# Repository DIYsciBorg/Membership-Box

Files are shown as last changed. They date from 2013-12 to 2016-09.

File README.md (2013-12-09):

Membership-Box
==============

A membership and donations payment box, utilizing Arduino, LCD, thermal printer and bill validator.

Arduino code: THS_Membership_Box.ino
EagleCAD files: .brd, .pro, .sch
Images of the board and schematic in png for quick viewing.

This is a membership payment and donation box. It is comprised of an Arduino with 
custom shield, 20x2 VFD display, two illuminated buttons, a thermal printer and a 
bill acceptor.

The bill acceptor is model NV10USB, by Innovative Technologies. It is programmed
to accept Japanese yen (1000, 5000, and 10000).

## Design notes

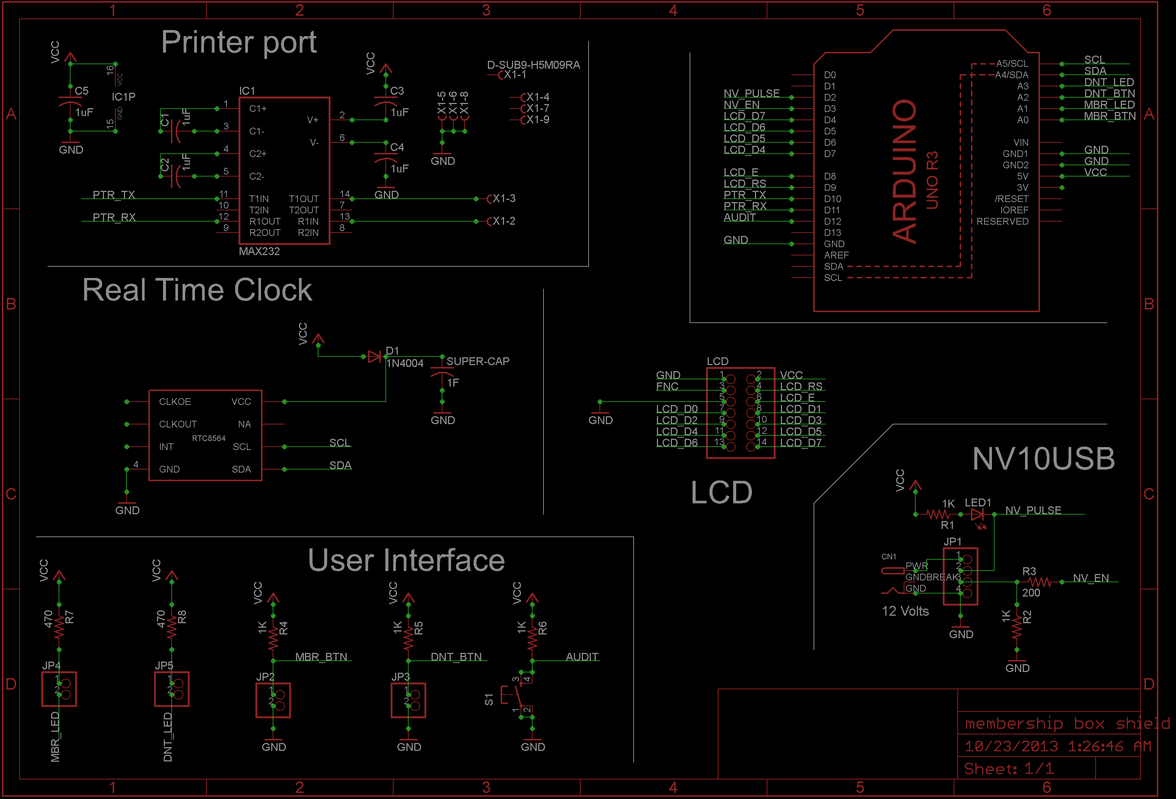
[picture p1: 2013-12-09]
Eagle/membership box schematic.png

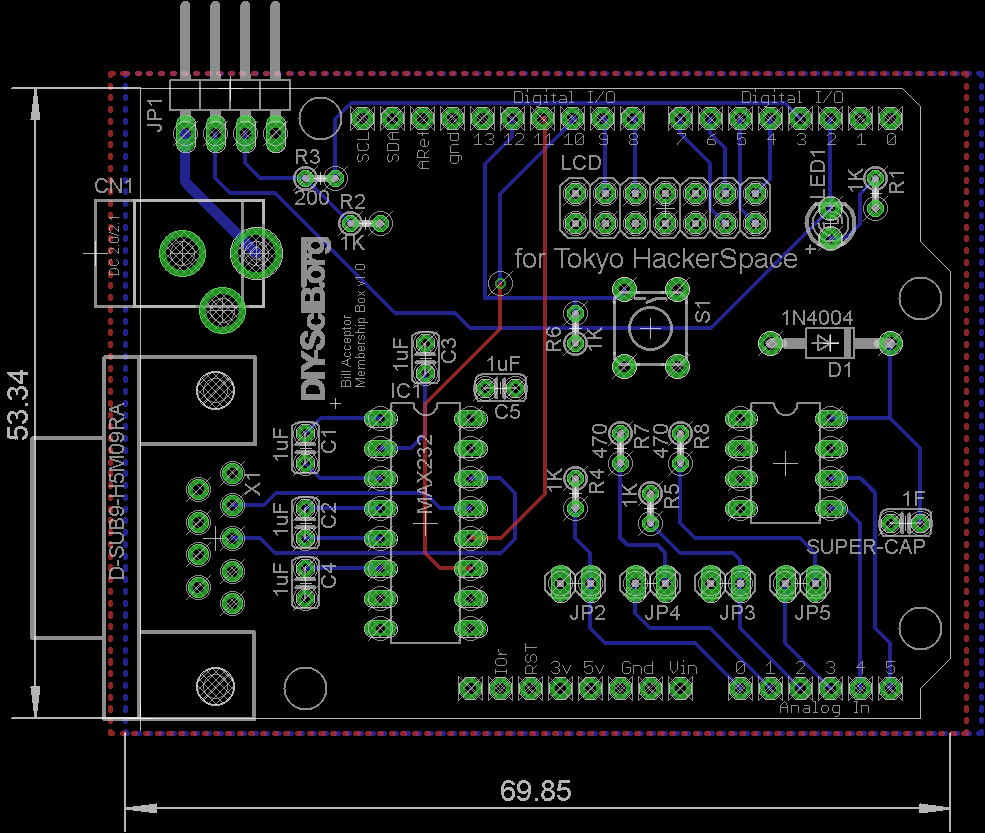
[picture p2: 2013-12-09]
Eagle/membership box pcb.png

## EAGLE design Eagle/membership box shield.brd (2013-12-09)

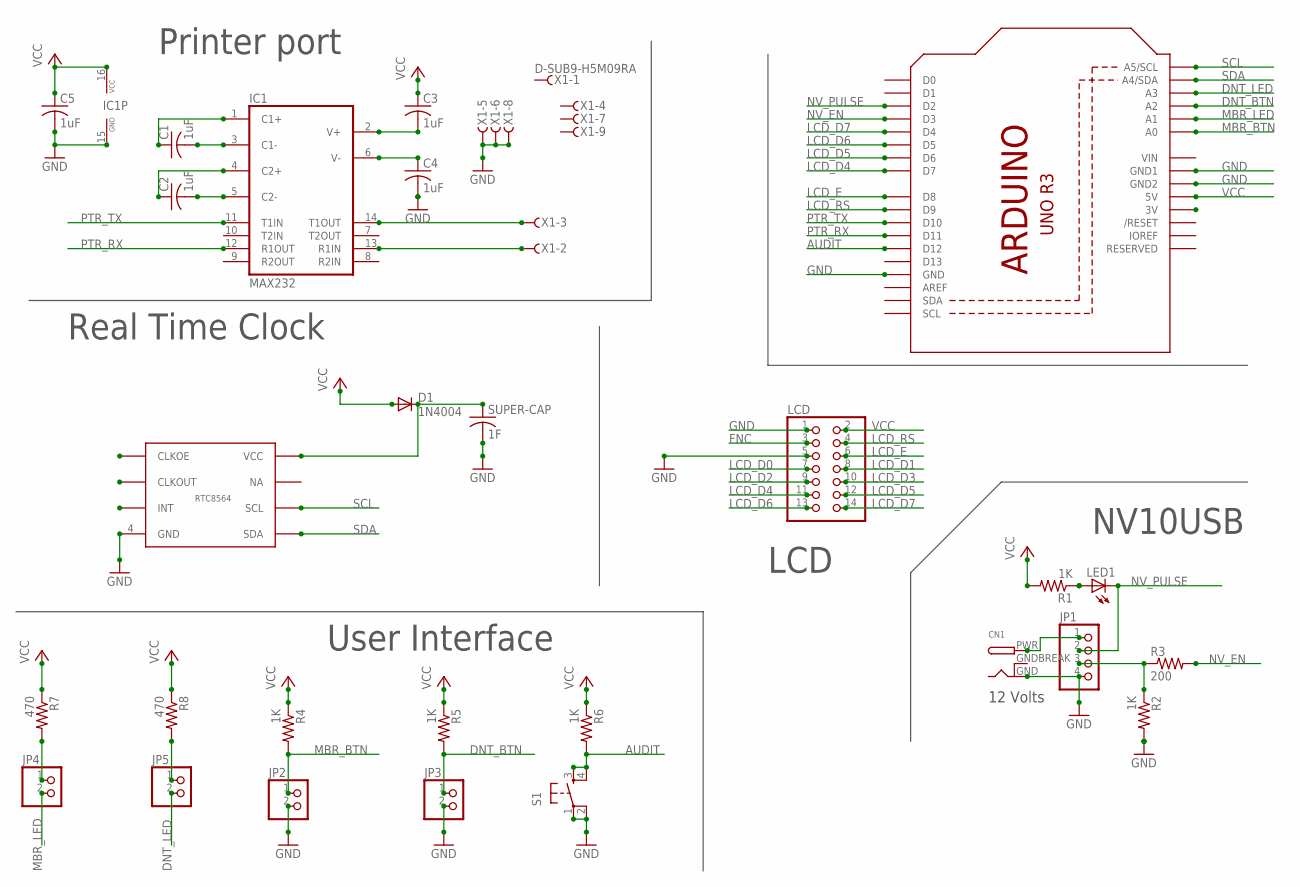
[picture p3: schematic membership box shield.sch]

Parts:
C1, C2, C3, C4, C5: 1uF; C025-024X044
CN1: DCBARRELPTH; DCJACK_2MM_PTH
D1: 1N4004; DO41-10
IC1: MAX232; DIL16
JP1: PINHD-1X4/90; 1X04/90
JP2, JP3, JP4, JP5: PINHD-1X2; 1X02
LCD: PINHD-2X7; 2X07
LED1: LED3MM
R1, R2, R4, R5, R6: 1K; 0204V
R3: 200; 0204V
R7, R8: 470; 0204V
RTC: RTC-8564_MODULE; DIP-8
S1: TAC_SWITCHPTH; TACTILE-PTH
SUPER-CAP: 1F; C025-024X044
U1: ARDUINOR3-DIMENSION; ARDUINOR3
X1: D-SUB9-H5M09RA; H5M09RA

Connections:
AUDIT: R6.2, S1.3, U1.D12
DNT_BTN: JP3.1, R5.2, U1.A2
DNT_LED: JP5.2, U1.A3
FNC: LCD.3
GND: C4.2, C5.2, CN1.GND, IC1.15 (GND), JP1.4, JP2.2, JP3.2, LCD.1, LCD.5, R2.2, RTC.4 (GND), S1.1, S1.2, SUPER-CAP.2, U1.GND, U1.GND1, U1.GND2, X1.5, X1.6, X1.8
GNDBREAK: CN1.GNDBREAK
LCD_D0: LCD.7
LCD_D1: LCD.8
LCD_D2: LCD.9
LCD_D3: LCD.10
LCD_D4: LCD.11, U1.D7
LCD_D5: LCD.12, U1.D6
LCD_D6: LCD.13, U1.D5
LCD_D7: LCD.14, U1.D4
LCD_E: LCD.6, U1.D8
LCD_RS: LCD.4, U1.D9
MBR_BTN: JP2.1, R4.2, U1.A0
MBR_LED: JP4.2, U1.A1
unnamed: JP1.3, R2.1, R3.1
unnamed: C1.2, IC1.3 (C1-)
unnamed: LED1.A, R1.1
unnamed: D1.C, RTC.8 (VCC), SUPER-CAP.1
unnamed: CN1.PWR, JP1.1
unnamed: C2.2, IC1.5 (C2-)
unnamed: IC1.13 (R1IN), X1.2
unnamed: JP4.1, R7.2
unnamed: JP5.1, R8.2
unnamed: C1.1, IC1.1 (C1+)
unnamed: IC1.14 (T1OUT), X1.3
unnamed: C2.1, IC1.4 (C2+)
unnamed: C3.2, IC1.2 (V+)
unnamed: C4.1, IC1.6 (V-)
NV_EN: R3.2, U1.D3
NV_PULSE: JP1.2, LED1.K (C), U1.D2
PTR_RX: IC1.12 (R1OUT), U1.D11
PTR_TX: IC1.11 (T1IN), U1.D10
SCL: RTC.6 (SCL), U1.A5 (A5/SCL)
SDA: RTC.5 (SDA), U1.A4 (A4/SDA)
VCC: C3.1, C5.1, D1.A, IC1.16 (VCC), LCD.2, R1.2, R4.1, R5.1, R6.1, R7.1, R8.1, U1.5V
VIN: U1.VIN

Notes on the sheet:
Printer port
Real Time Clock
User Interface
LCD
NV10USB
12 Volts

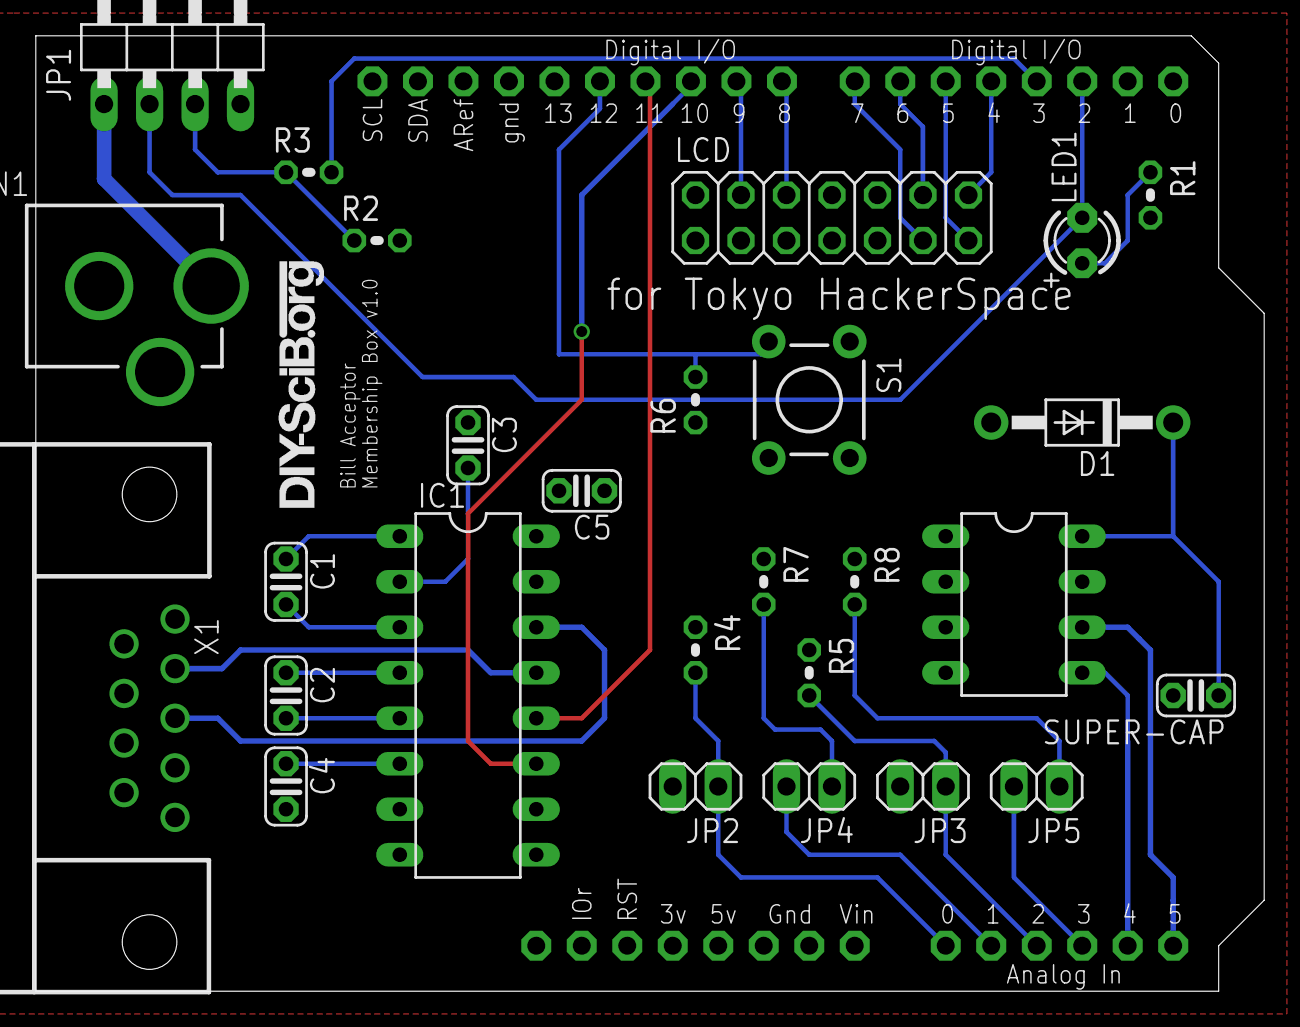
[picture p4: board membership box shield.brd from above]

Board: 2 copper layers, 68.6 x 53.3 mm, 29 parts (0 on the bottom side), 33 nets.

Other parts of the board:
U$1: DIYSCIB.ORG-LONG

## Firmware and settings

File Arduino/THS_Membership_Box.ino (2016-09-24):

/* Tokyo HackerSpace Membership payment box
      Written by Emery Premeaux
      DIY-SciB.org
      TokyoHackerSpace.org
    
      This project is open source
      Feel free to use, modify or redistribute
      It would be nice if you keep the original
      author information above.  ;)
      
      Written on Arduino v 1.10
      date: 9/25/16
*/
    
const float ver = 1.10;

/* clock settings
    If the clock is not running on bootup (backup battery died),
    Set the clock with these values:  */
int setYear    =  0x16;
int setMonth   =  0x09;
int setDay     =  0x18;
int setWeekday =  0x00; // 0:Sunday
int setHour    =  0x18;
int setMinute  =  0x04;
int setSecond  =  0x00;

/*    
    PINS:
    D0 - 1 debug serial          A0 - Membership payment button
    D2 - Pulse from BA           A1 - Membership LED
    D3 - BA Enable               A2 - Donation button
    D4 - LCD 7                   A3 - Donate LED
    D5 - LCD 6                   A4 - RTC SDA
    D6 - LCD 5                   A5 - RTC SCL
    D7 - LCD 4
    D8 - LCD E
    D9 - LCD RS
    D10 - printer serial TX
    D11 - printer serial RX
    D12 - audit button
    D13 - debugging
*/

// HARDWARE startups
#include <SoftwareSerial.h>
#include "Adafruit_Thermal.h"
#define TX_PIN 10
#define RX_PIN 11
SoftwareSerial mySerial(RX_PIN, TX_PIN);
Adafruit_Thermal printer(&mySerial);  // RX, TX

#include <LiquidCrystal.h>
LiquidCrystal lcd(9, 8, 7, 6, 5, 4);
#include <EEPROM.h>

#include "DIYSciBorg_RTC8564.h"
#include  <Wire.h>

RTC myClock;

// PIN defines
const int ledPin = 13;
const int BApulse = 2;
const int BAenable = 3;
const int printerTX = 10;
const int printerRX = 11;
const int auditBtn = 12;
const int debuggingLED = 13;
const int membershipBtn = 14;
const int membershipLED = 15;
const int donateBtn = 16;
const int donateLED = 17;

// attract mode variables
byte msgNumber= 0;
long previousAttractMillis = 0;
long attractInterval = 10000;

// Bill insertion and wait
unsigned int cashCount = 0;  // counter for cash inserted
unsigned int previousCashCount = 0;
long previousInsertMillis = 0;
long insertInterval = 1000; // wait for 10000 yen bills

// Button press debugging
long previousPressMillis = 0;
long pressInterval = 1000;

// EEPROM data locations
const int donationAudit = 0;
const int membershipAudit = 1;
const int escrowAudit = 2;
const int transactionAudit = 3;

// NV10USB constants
const int BAon = LOW;
const int BAoff = HIGH;


/***************** Reuseable strings *****************/
/* This is where code action starts. However, because the 
String to FLASH option does not work outside the calling function
we need to set up some quick print functions.
The goal here is to save RAM.
You will find Setup further down.
*/
void txtTHS(){
  printer.println(F("TokyoHackerSpace"));}
void txtSorry(){
  printer.println(F("Sorry. No prize."));}
void txtWinner(){
  printer.println(F("You are a WINNER!"));}
void txtWrite1(){
  printer.println(F("Write your name on this"));}
void txtWrite2(){
  printer.println(F("receipt. Insert it in the box."));}
void txtWrite3(){
  printer.println(F("Name: ________________________"));}
void txtWrite4(){
  printer.println(F("-------------TEAR-------------"));}


/***************** Let's get going! *****************/
void setup()
{
  mySerial.begin(19200);
  printer.begin();
  
  lcd.begin(20, 2);
  lcd.print("THS Payment Box");
  lcd.setCursor(6,1);
  lcd.print("ver: ");
  lcd.print(ver);
  Wire.begin();
  int Status = myClock.isRunning();
    // if unset, then set the clock
    if (Status == false){
      myClock.reset();   // sets all registeres in stable states
                  //year, month, day, weekday, hour, minute, second
      myClock.setTime(setYear, setMonth, setDay, setWeekday, setHour, setMinute, setSecond);
    }
  lcd.setCursor(0,1);
  lcd.print("clock is running");
  delay(1000);
  pinMode(ledPin, OUTPUT);
  pinMode(BAenable, OUTPUT);
  pinMode(auditBtn, INPUT);
  pinMode(debuggingLED, OUTPUT);
  pinMode(membershipBtn, INPUT);
  pinMode(membershipLED, OUTPUT);
  pinMode(donateBtn, INPUT);
  pinMode(donateLED,OUTPUT);
  
  digitalWrite(donateLED, HIGH);
  digitalWrite(membershipLED, HIGH);
  digitalWrite(BAenable, BAoff);
  
  printer.begin();
  lcd.setCursor(0,1); 
  lcd.print("printer is running");
  delay(1000);
  attachInterrupt(0, caChing, FALLING);
  
  delay(3000);          // Wait for the BA to boot
 // EEPROM.write(escrowAudit, 0);   // just long enough to clear the eeprom. then remove and upload
  cashCount = EEPROM.read(escrowAudit); 
  lcd.setCursor(0,1);
  lcd.print("EEPROM checked");
  delay(1000);
}

/************** what to do in ISR **************/
void caChing()
{
  delay(45);
  if(digitalRead(BApulse)==LOW){
    cashCount++;    // for every bill pulse, add 1
    cashIn();
  }
}

/************** Mainline **************/
void loop(){
 digitalWrite(ledPin, HIGH);
 digitalWrite(BAenable, BAon);
 
  if(cashCount == 0){
    digitalWrite(ledPin, LOW);
    idling();
  }
  if(cashCount != previousCashCount){
    digitalWrite(ledPin, LOW);
    cashIn();
  }
  if(cashCount != 0 && digitalRead(donateBtn) == LOW){
    unsigned long currentPressMillis = millis();
    if(currentPressMillis - previousPressMillis > pressInterval){
      previousPressMillis = currentPressMillis;
      digitalWrite(BAenable, BAoff);
      donateProcess();
    }
  }
  if(cashCount >= 5 && digitalRead(membershipBtn) == LOW){
    unsigned long currentPressMillis = millis();
    if(currentPressMillis - previousPressMillis > pressInterval){
      previousPressMillis = currentPressMillis;
      digitalWrite(BAenable, BAoff);
      membershipProcess();
    }
  }
  if(cashCount == 0 && digitalRead(auditBtn) == LOW){
    unsigned long currentPressMillis = millis();
    if(currentPressMillis - previousPressMillis > pressInterval){
      previousPressMillis = currentPressMillis;
      digitalWrite(BAenable, BAoff);
      auditProcess();
    }
  }
}        // keep it short and sweet!


/************** Audit Process **************/
void auditProcess(){
  digitalWrite(BAenable, BAoff);    // disable the acceptor
  lcd.clear();
  lcd.print("Audit mode!");
  delay(1000);
  lcd.clear();
  lcd.print("Dnt: ");
  lcd.print(EEPROM.read(donationAudit));
  lcd.setCursor(11,0);
  lcd.print("Mbrs: ");
  lcd.print(EEPROM.read(membershipAudit));
  lcd.setCursor(0,1);
  lcd.print("EXT:Audit");
  lcd.setCursor(11,1);
  lcd.print("Clr:Mbrs");
  
  int holdingPattern = 1;
  while (holdingPattern = 1){
    digitalWrite(membershipLED, LOW);
  if(digitalRead(auditBtn) == LOW){
    unsigned long currentPressMillis = millis();
    if(currentPressMillis - previousPressMillis > pressInterval){
      previousPressMillis = currentPressMillis;
      holdingPattern = 0;
      lcd.clear();
      lcd.print("Audits preserved!");
      delay(1000);
      digitalWrite(membershipLED, HIGH);
      digitalWrite(BAenable, BAon);  // enable the acceptor
      break;
    }
  }
  if(digitalRead(membershipBtn) == LOW){
    unsigned long currentPressMillis = millis();
    if(currentPressMillis - previousPressMillis > pressInterval){
      previousPressMillis = currentPressMillis;
      holdingPattern = 0;
      digitalWrite(membershipLED, HIGH);
      clearAudits();
      digitalWrite(BAenable, BAon);  // enable the acceptor
      break;
    }
  }
 }
}

/************** Clear Audits **************/
void clearAudits(){
 EEPROM.write(donationAudit, 0);
 EEPROM.write(membershipAudit, 0);
 lcd.clear();
 lcd.print("Audits cleared!");
 delay(1000);
}


/************** Donate Process **************/
void donateProcess(){
  digitalWrite(BAenable, BAoff);
  printer.wake();
  lcd.clear();
  lcd.print("Thank you for your");
  lcd.setCursor(5,1);
  lcd.print("DONATION!");
  cashCount--;
  
  int donationValue = EEPROM.read(donationAudit);
  if (donationValue == 255){
    donationValue = 0;}
  donationValue++;
  EEPROM.write(donationAudit, donationValue);
  
  int transactionNumber = EEPROM.read(transactionAudit);
  if (transactionNumber == 255){
    transactionNumber = 0;}
  transactionNumber++;
  EEPROM.write(transactionAudit, transactionNumber);
  
  delay(1000);
  lcd.clear();
  lcd.print("We've had ");
  lcd.print(EEPROM.read(donationAudit));
  lcd.setCursor(0,1);
  lcd.print("donations this month");
  delay(1000);
  printDonation();
  cashIn();
}

/************** Memebership Process **************/
void membershipProcess(){
  digitalWrite(BAenable, BAoff);
  printer.wake();
  lcd.clear();
  lcd.print("Printing receipts");
  cashCount = (cashCount - 5);
  
  int membershipValue = EEPROM.read(membershipAudit);
  if (membershipValue == 255){
    membershipValue = 0;}
  membershipValue++;
  EEPROM.write(membershipAudit, membershipValue);
  
  int transactionNumber = EEPROM.read(transactionAudit);
  if (transactionNumber == 255){
    transactionNumber = 0;}
  transactionNumber++;
  EEPROM.write(transactionAudit, transactionNumber);
  
  delay(1000);
  myClock.getTime();
  printTHScopy();
  printMembership();
  cashIn();
}
/************** Idling - attract **************/
void idling(){
 /* Here we put various attract messages on the screen
 while idling away with nothing else to do.
 */
 unsigned long currentAttractMillis = millis();
 if(currentAttractMillis - previousAttractMillis > attractInterval){
   previousAttractMillis = currentAttractMillis;
   switch (msgNumber) {
     case 0:
       lcd.clear();
       lcd.print("Make a donation!");
       msgNumber++;
       break;
     case 1:
       lcd.clear();
       lcd.print("Pay membership here!");
       msgNumber++;
       break;
     case 2:
       lcd.clear();
       lcd.print("Yo! Help us out!");
       msgNumber++;
       break;
       }
  lcd.setCursor(0,1);
  myClock.getTime();
  lcd.print(myClock.Year, HEX);
  lcd.print("/");
  lcd.print(myClock.Month, HEX);
  lcd.print("/");
  lcd.print(myClock.Day, HEX);
  lcd.print(" ");
  lcd.print(myClock.Hour);
  lcd.print(":");
  lcd.print(myClock.Minute);
 }
 if(msgNumber >= 3){  // set number of messages and resets
   msgNumber = 0;
 }
}


/************** CashIn **************/
void cashIn(){
  previousCashCount = cashCount;
  lcd.clear();
  lcd.print("You have ");
  lcd.print(cashCount * 1000);
  lcd.print(" yen!");
  setLEDs();
  EEPROM.write(escrowAudit, cashCount); 
}


/************** Set LEDs **************/
void setLEDs(){
  if(cashCount == 0){
    digitalWrite(donateLED, HIGH);
    digitalWrite(membershipLED, HIGH);
  }else if(cashCount < 5){
    digitalWrite(donateLED, LOW);
    digitalWrite(membershipLED, HIGH);
  }else{
      digitalWrite(donateLED, LOW);
      digitalWrite(membershipLED, LOW);
  } 
}

/********* Print member's receipt *********/
void printMembership(){
  lcd.clear();
  lcd.print("Keep this copy");
  
  printer.setSize('L');
  txtTHS();
  printer.setSize('M');
  printer.println("Member's Copy");
  printer.print("Receipt #M");
  printer.println(EEPROM.read(transactionAudit));
  printer.setSize('S');
  printer.print("Date: ");
  printer.print(myClock.Year, HEX);
  printer.print("/");
  printer.print(myClock.Month, HEX);
  printer.print("/");
  printer.println(myClock.Day, HEX);
  printer.print("Time: ");
  printer.print(myClock.Hour);
  printer.print(":");
  printer.println(myClock.Minute);
          // fill with date printing code later
  printer.feed(3);
  printer.println("Keep this receipt!");
  printer.println("This is to certify that you paid");
  printer.println("a 5000 yen membership.");
  printer.feed(3);
  txtWrite4();
  printer.feed(3);
  
}

/********* Print THS's receipt ***********/
void printTHScopy(){
  lcd.clear();
  lcd.print("Sign this one");
  lcd.setCursor(0, 1);
  lcd.print("Put in the slot");
  
  printer.setSize('L');
  txtTHS();
  printer.setSize('M');
  printer.println("Admin Copy");
  printer.print("Receipt #M");
  printer.println(EEPROM.read(transactionAudit));
  printer.setSize('S');
  printer.print("Date: ");
  printer.print(myClock.Year, HEX);
  printer.print("/");
  printer.print(myClock.Month, HEX);
  printer.print("/");
  printer.println(myClock.Day, HEX);
  printer.print("Time: ");
  printer.print(myClock.Hour);
  printer.print(":");
  printer.println(myClock.Minute);
  printer.feed(3);
  txtWrite1();
  txtWrite2();
  printer.feed(3);
  txtWrite3();
  printer.feed(3);
  txtWrite4();
  printer.feed(3);
  delay(2500);
}

/********* Print Donation receipt ***********/
void printDonation(){
  lcd.clear();
  lcd.print("Donation Receipt");
  
  printer.setSize('L');
  txtTHS();
  printer.setSize('M');
  printer.println("1000 yen Donation!");
  printer.print("Receipt #D");
  printer.println(EEPROM.read(transactionAudit));
  printer.setSize('S');
  myClock.getTime();
  printer.print("Date: ");
  printer.print(myClock.Year, HEX);
  printer.print("/");
  printer.print(myClock.Month, HEX);
  printer.print("/");
  printer.println(myClock.Day, HEX);
  printer.print("Time: ");
  printer.print(myClock.Hour);
  printer.print(":");
  printer.println(myClock.Minute);
  printer.feed(1);
  printer.println("(^_^)     (^_^)     (^_^)");
  printer.println();
  printer.println("Thank you for your donation.");
  printer.println("It will help us pay the bills.");
  printer.feed(3);
  txtWrite4();
  printer.feed(3);
}

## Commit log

2013-12-09 0.9
    PCB designs fixed. Code nearly ready
    [membership box shield.brd, membership box shield.sch]
2014-01-13 v1.042
    * Improved interrupt handling to deal with static issues
    * Corrected a receipt print routine to print the name space
    [THS_Membership_Box.ino]
2014-01-13 v1.02
    * Improved interrupt service routine to deal with static causing false
    bill inserts
    * Corrected a receipt printing routine to include the name field
    [THS_Membership_Box.ino]
2014-01-13 v1.02 proper
    * Improved ISR to deal with static causing false bill inserts
    * Corrected a print routine
    [THS_Membership_Box.ino]
2014-01-26 v1.03
    * Added printer wake
    * Added donation printing
    * Modified the audit menu
2016-09-24 update to new printer and v1.0.4 arduino ide
    fixes all new IDE issues, upgrades to new thermal printer
    [THS_Membership_Box.ino]

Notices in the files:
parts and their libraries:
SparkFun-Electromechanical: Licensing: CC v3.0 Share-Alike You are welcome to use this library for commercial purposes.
